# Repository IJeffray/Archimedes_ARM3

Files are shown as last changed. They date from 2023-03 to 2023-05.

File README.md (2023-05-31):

# Acorn Archimedes ARM3 processor card

May 2023

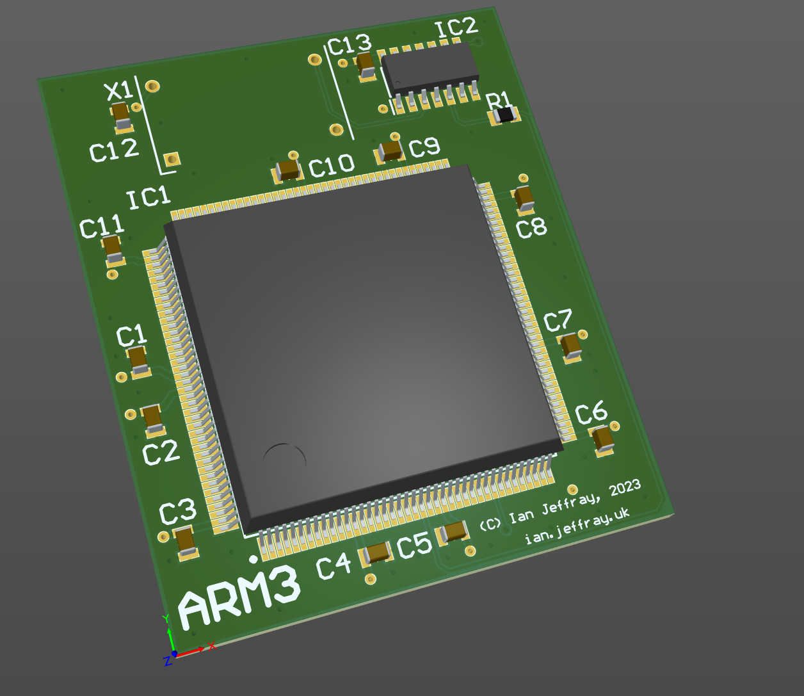
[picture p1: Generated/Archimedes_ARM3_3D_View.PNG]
3D View


This is my implementation of an ARM3 upgrade card that will plug in to the ARM2 socket on early model Acorn Archimedes machines.

The 1.0 release has been tested successfully over 8 builds using 25MHz and 33MHz parts recovered from dead A5000 machines.  An issue was noted in A4xx/1 machines - the machine will not start due to a missed ABORT pin connection - this issue is specific to the A4xx/1 and corrected in version 1.1 of the design.  A The 1.1 release has been tested successfully in 3 builds with 25MHz parts.

## Licence

No warranty is provided, and this work is used at your own risk.  

Licenced as CC BY-SA 3.0

Copyright 2023 Ian Jeffray

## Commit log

2021-05-23 Initial check in
    [ARM2toARM3Adapter.PrjPcb, ARM2toARM3Adapter.SchDoc, ARM2toARM3Adapter.pcbdoc]
2021-05-23 Replace PL1 footprint with hand-made version, matchnig the part datasheet.
    [ARM2toARM3Adapter.PrjPcb, ARM2toARM3Adapter.SchDoc, ARM2toARM3Adapter.pcbdoc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]
2021-05-31 Update schematic template
    [ARM2toARM3Adapter.SchDoc]
2021-06-01 Tidy up the layout a bit - more accurate polygon definitions and improved routing to reduce dead copper and allow more contiguous ground copper
    [ARM2toARM3Adapter.SchDoc, ARM2toARM3Adapter.pcbdoc]
2021-06-02 Correct missing pin on ARM3 (GND). Tidy pin names on symbols for ARM2 and ARM3. Add JLC label on layout.
    [ARM2toARM3Adapter.PrjPcb, ARM2toARM3Adapter.SchDoc, ARM2toARM3Adapter.pcbdoc]
2021-06-02 Tweak output settings
    [ARM2toARM3Adapter.PrjPcb, ARM2toARM3Adapter.pcbdoc]
2021-06-02 Fixed missed net for ABORT pin. Cleaned up pin mapping for PLCC84 plug (reversed footprint)
    [ARM2toARM3Adapter.PrjPcb, ARM2toARM3Adapter.SchDoc, ARM2toARM3Adapter.pcbdoc]
2023-02-14 Removed useless polarity protection. Change R1 to 0805 size. Change all vias to 4mm drill for cheaper manufacture. Add missed /CPI pull to VCC (for A4xx/1 compatibility).
    [ARM2toARM3Adapter.SchDoc, ARM2toARM3Adapter.pcbdoc]
2025-10-02 Routing tweaks. Reduce board size. 0603 caps.
    [ARM2toARM3Adapter.PrjPcb, ARM2toARM3Adapter.SchDoc, ARM2toARM3Adapter.pcbdoc]
2025-10-02 Remove junked files
    [PcbLib1.PcbLib]
